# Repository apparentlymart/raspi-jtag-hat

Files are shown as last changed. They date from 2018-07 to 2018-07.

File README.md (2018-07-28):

# Raspberry Pi 3 Bare Metal Dev HAT

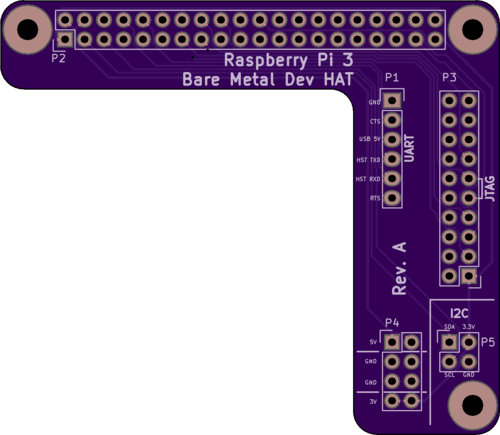
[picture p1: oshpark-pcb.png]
Bare Metal Dev HAT PCB


This repository contains KiCad design files for an **experimental** Raspberry
Pi "pseudo-HAT" (lacking an ID EEPROM) that breaks out the JTAG and UART pins
to an ARM-style JTAG header and a 6-pin "FTDI header" respectively. The goal
is to make it easy to connect diagnostic tools from a host development machine
when working on bare-metal software for the Raspberry Pi 3.

The author makes no promises or warranty about the quality or functionality of
this PCB design. Your mileage may vary. However, if you would like to give it a
try, either clone the repo and load the project into KiCad or download the
Gerber files attached to one of the
[tagged revisions](https://github.com/apparentlymart/raspi-jtag-hat/releases).
Before spending any time and money, please consider checking for any
[open issues](https://github.com/apparentlymart/raspi-jtag-hat/issues), and
for any _closed_ issues that apply to the tagged revision you are working with.

The board also includes extra breakouts for the I2C pins and the power pins
from the main header, as an optional convenience. It might also work for
Raspberry Pi 2, but its unusual L-shape is intended to avoid conflicts with
the larger heatsinks that some owners fit to their Raspberry Pi 3 units.

The following is an example BOM for some through-hole components that could
be used to populate this PCB:

| Ref. | Description | Octopart Id |
| ---- | --- | --- |
| P1 | "FTDI-style" UART header | [22-28-4063-molex-278209](https://octopart.com/22-28-4063-molex-278209) |
| P2 | Raspberry Pi Main header socket | [hif3h-40da-2.54dsa(71)-hirose-22821340](https://octopart.com/hif3h-40da-2.54dsa%2871%29-hirose-22821340) |
| P3 | "ARM-style" JTAG socket | [htst-110-01-l-d-samtec-6823793](https://octopart.com/htst-110-01-l-d-samtec-6823793) |
| P4 | Misc. Power header | [10-89-7082-molex-20831](https://octopart.com/10-89-7082-molex-20831) |
| P5 | I2C header | [10-89-7042-molex-35512](https://octopart.com/10-89-7042-molex-35512) |
| n/a  | Board Spacer (optional) | [mdlsp3-6-01-essentra-33826524](https://octopart.com/mdlsp3-6-01-essentra-33826524) |

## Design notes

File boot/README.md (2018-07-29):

# JTAG init kernel

This directory contains the source code for a very small kernel.img that just
prints a greeting message to the UART, enables the ALT4 functions on the JTAG
pins, and then halts the CPU awaiting instructions from a connected JTAG
adapter.

To build it you will need an `aarch64-linux-gnu` toolchain including `gcc`,
`as`, `ld`, and `objcopy`. Ubuntu Xenial has packages for this named
`gcc-4.8-aarch64-linux-gnu` or `gcc-4.9-aarch64-linux-gnu`.

Build by running `make`, populate the boot partition of your Raspberry Pi
SD card with
[the standard Raspberry Pi firmware](https://github.com/raspberrypi/firmware/tree/master/boot),
and then copy the contents of the generated `bootfs` subdirectory into the boot
partition. This will overwrite two files in the stock firmware:
[the `config.txt` file](https://www.raspberrypi.org/documentation/configuration/config-txt/)
and the Linux kernel image for the Pi 1, Pi Zero, and Compute Module.

The `config.txt` contains `enable_jtag_gpio=1`, which actually enables the
JTAG pin functions earlier on suitably-modern firmware. The code in `kernel.img`
will then configure the pin functions again to make sure.

If all goes to plan and you have a terminal program listening to the UART
you should see the following message on the serial port at boot:

```
Enabling JTAG
```

To make use of this you will need a build of OpenOCD that has `aarch64` support
and a Raspberry Pi 3 target file. At the time of writing neither is included
in a released version of OpenOCD, but you can build
[daniel-k's fork](https://github.com/daniel-k/openocd) (branch armv8) to get
the necessary support to launch OpenOCD. Since I'm using a
[Segger J-Link](https://www.segger.com/products/debug-probes/j-link/) adapter,
my launch command is as follows. You will need to change the first path
to a different interface configuration if you are using a different adapter.

```
openocd -f interface/jlink.cfg -f target/rpi3.cfg
```

With OpenOCD running you can connect an aarch64-targeting `gdb` to the OpenOCD
gdbserver:

```
$ aarch64-linux-gnu-gdb
GNU gdb (GDB) 8.1
Copyright (C) 2018 Free Software Foundation, Inc.
License GPLv3+: GNU GPL version 3 or later <http://gnu.org/licenses/gpl.html>
This is free software: you are free to change and redistribute it.
There is NO WARRANTY, to the extent permitted by law.  Type "show copying"
and "show warranty" for details.
This GDB was configured as "--host=x86_64-pc-linux-gnu --target=aarch64-linux-gnu".
Type "show configuration" for configuration details.
For bug reporting instructions, please see:
<http://www.gnu.org/software/gdb/bugs/>.
Find the GDB manual and other documentation resources online at:
<http://www.gnu.org/software/gdb/documentation/>.
For help, type "help".
Type "apropos word" to search for commands related to "word".
(gdb) file yourprogram.elf
Reading symbols from toyos.elf...done.
(gdb) monitor targets rpi3.cpu
(gdb) monitor halt
(gdb) load_image yourprogram.img 0 bin
(gdb) monitor reset halt
(gdb) monitor reg pc 0
(gdb) c
```

In the above `yourprogram.elf` and `yourprogram.img` are both different forms
of the program you wish to run and debug on the Raspberry Pi 3. The former is
in ELF format and used locally by `gdb`, while the latter is the raw binary
image that is loaded into the Raspberry Pi's memory and executed.

The `monitor` commands run direct OpenOCD commands. You can run `monitor help`
to see the usage information for all of these.

Once you get `gdb` working and get comfortable with it you can load and execute
bare metal code on your Raspberry Pi directly from your development machine,
without constantly swapping and rewriting SD cards, configuring netboot, etc.

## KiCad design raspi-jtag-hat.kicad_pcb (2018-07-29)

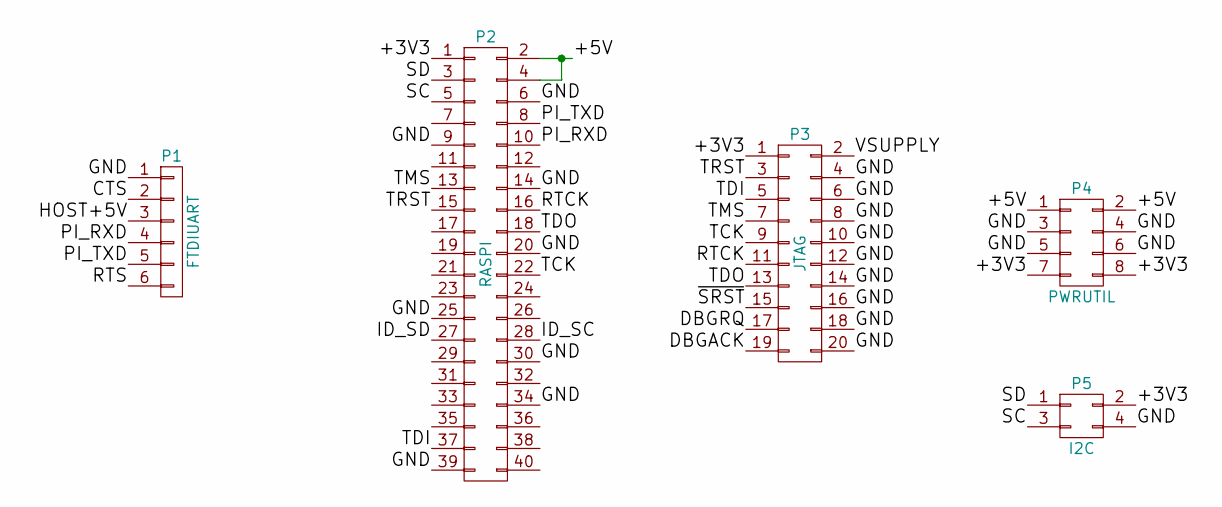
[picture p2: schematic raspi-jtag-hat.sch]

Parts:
P1: FTDIUART
P2: RASPI
P3: JTAG
P4: PWRUTIL
P5: I2C

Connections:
/+3V3: P2.1, P3.1, P4.7, P4.8, P5.2
/+5V: P2.2, P2.4, P4.1, P4.2
/CTS: P1.2
/DBGACK: P3.19
/DBGRQ: P3.17
/GND: P1.1, P2.6, P2.9, P2.14, P2.20, P2.25, P2.30, P2.34, P2.39, P3.4, P3.6, P3.8, P3.10, P3.12, P3.14, P3.16, P3.18, P3.20, P4.3, P4.4, P4.5, P4.6, P5.4
/HOST+5V: P1.3
/ID_SC: P2.28
/ID_SD: P2.27
/PI_RXD: P1.4, P2.10
/PI_TXD: P1.5, P2.8
/RTCK: P2.16, P3.11
/RTS: P1.6
/SC: P2.5, P5.3
/SD: P2.3, P5.1
/TCK: P2.22, P3.9
/TDI: P2.37, P3.5
/TDO: P2.18, P3.13
/TMS: P2.13, P3.7
/TRST: P2.15, P3.3
/VSUPPLY: P3.2
/~SRST: P3.15

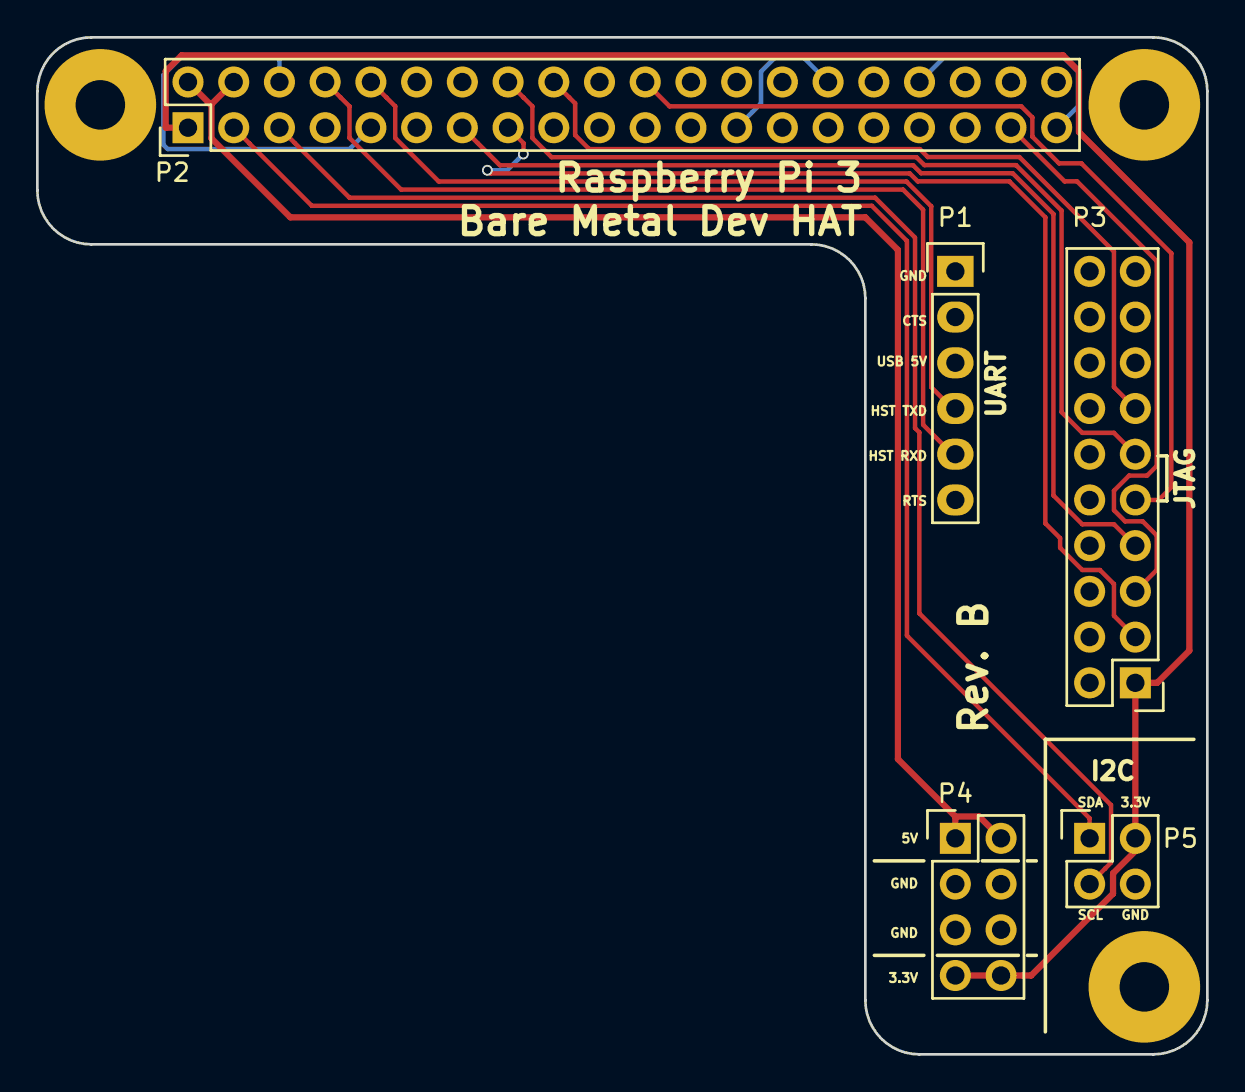
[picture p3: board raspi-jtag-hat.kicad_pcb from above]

Board: 2 copper layers, 65.0 x 56.5 mm, 5 parts (0 on the bottom side), 13 nets.

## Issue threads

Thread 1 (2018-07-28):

JTAG connector is vertically mirrored

apparentlymart, 2018-07-28:
In the Revision A design, the JTAG connector positions are vertically mirrored such that the JTAG connector would need to attach underneath the board rather than on top.

This is physically impossible when mounted on top of a Raspberry Pi as intended. All of the pin positions should be flipped vertically so that pin 1 is at the top right of the connector when viewing the board from the top side.

apparentlymart, 2018-07-29:
This was a false alarm: my test setup was the one that was vertically mirrored. Revision A appears to have the connector correctly oriented after all.

Closed 2018-07-29.

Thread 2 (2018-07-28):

JTAG connector may interfere with Pi 3+ PoE header

apparentlymart, 2018-07-28:
The Raspberry Pi 3+ design introduced a new PoE header just under the top right mounting hole on the main Pi board.

I have not yet verified whether the JTAG connector interferes with either of the lower pins on that connector. Based on the reported positions it seems possible that the top right connector on the header could short to the bottom right pin on the PoE header.

To be determined once I have both a Pi 3+ board and a JTAG HAT board at the same time/

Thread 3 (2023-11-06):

Seems to work on Compute Module 4 with the official I/O board

apparentlymart, 2023-11-06:
Today I've been successfully using a previously-assembled Rev B board (by coincidence, the one I used to verify #2) to interact with a Compute Module 4 through the "HAT headers" on the I/O board.

Both the JTAG and UART connections work. Seems that the pinout is the same as for Raspberry Pi 3. Perhaps the next revision should just say "Raspberry Pi Bare Metal Dev HAT" to avoid seeming like it's only for Pi 3.

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

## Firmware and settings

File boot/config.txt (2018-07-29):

arm_control=0x200
kernel=kernel.img
kernel_old=1
disable_commandline_tags=1
enable_jtag_gpio=1

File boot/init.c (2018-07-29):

/*
 * Derived from code:
 *
 * https://github.com/swarren/rpi-3-aarch64-demo
 * Copyright (C) 2012 Vikram Narayananan <vikram186@gmail.com>
 * (C) Copyright 2012-2016 Stephen Warren
 * Copyright (C) 1996-2000 Russell King
 *
 * SPDX-License-Identifier:	GPL-2.0
 *
 * https://github.com/dwelch67/raspberrypi/tree/master/armjtag
 * Copyright (c) 2012 David Welch dwelch@dwelch.com
 */

#include <stdint.h>

#define BIT(x) (1U << (x))

#define PERI_BASE (0x3F000000)

#define MU_BASE (PERI_BASE + 0x00215040)
#define MU_LSR_TX_NOT_FULL (BIT(5))
#define MU_LSR_RX_READY (BIT(0))

#define AUX_ENABLES (PERI_BASE + 0x00215004)
#define AUX_MU_IO_REG (PERI_BASE + 0x00215040)
#define AUX_MU_IER_REG (PERI_BASE + 0x00215044)
#define AUX_MU_IIR_REG (PERI_BASE + 0x00215048)
#define AUX_MU_LCR_REG (PERI_BASE + 0x0021504C)
#define AUX_MU_MCR_REG (PERI_BASE + 0x00215050)
#define AUX_MU_LSR_REG (PERI_BASE + 0x00215054)
#define AUX_MU_MSR_REG (PERI_BASE + 0x00215058)
#define AUX_MU_SCRATCH (PERI_BASE + 0x0021505C)
#define AUX_MU_CNTL_REG (PERI_BASE + 0x00215060)
#define AUX_MU_STAT_REG (PERI_BASE + 0x00215064)
#define AUX_MU_BAUD_REG (PERI_BASE + 0x00215068)

#define GPFSEL0 (PERI_BASE + 0x00200000)
#define GPFSEL1 (PERI_BASE + 0x00200004)
#define GPFSEL2 (PERI_BASE + 0x00200008)
#define GPSET0 (PERI_BASE + 0x0020001C)
#define GPCLR0 (PERI_BASE + 0x00200028)
#define GPPUD (PERI_BASE + 0x00200094)
#define GPPUDCLK0 (PERI_BASE + 0x00200098)
#define GPPUDCLK1 (PERI_BASE + 0x0020009C)

#define GPFSEL_PIN_MASK (7U) //(BIT(2) | BIT(1) | BIT(0))
#define GPFSEL_ALT_4 (3U)    //(BIT(1) | BIT(0))
#define GPFSEL_ALT_5 (2U)    //(BIT(1))

#define __arch_getl(a) (*(volatile unsigned int *)(a))
#define __arch_putl(v, a) (*(volatile unsigned int *)(a) = (v))

#define dmb() __asm__ __volatile__("dmb st" : : : "memory")
#define nop() __asm__ __volatile__("nop")
#define wfi() __asm__ __volatile__("wfi")
#define __iormb() dmb()
#define __iowmb() dmb()

struct bcm283x_mu_regs {
    uint32_t io;
    uint32_t iir;
    uint32_t ier;
    uint32_t lcr;
    uint32_t mcr;
    uint32_t lsr;
    uint32_t msr;
    uint32_t scratch;
    uint32_t cntl;
    uint32_t stat;
    uint32_t baud;
};

static inline uint32_t readl(uint64_t addr)
{
    uint32_t value = __arch_getl(addr);
    __iormb();
    return value;
}

static inline void writel(uint64_t addr, uint32_t value)
{
    __arch_putl(value, addr);
    __iowmb();
}

static void bcm283x_mu_serial_putc(const char data)
{
    struct bcm283x_mu_regs *regs = (struct bcm283x_mu_regs *)MU_BASE;

    /* Wait until there is space in the FIFO */
    while (!(readl((uint64_t)&regs->lsr) & MU_LSR_TX_NOT_FULL))
        ;

    /* Send the character */
    writel((uint64_t)&regs->io, data);
}

static void dbg_puts(const char *s)
{
    while (*s)
        bcm283x_mu_serial_putc(*s++);
}

static void enable_af_pins(int clock, uint32_t bitmask)
{
    uint32_t clock_reg;
    int i;

    switch (clock) {
    case 0:
        clock_reg = GPPUDCLK0;
        break;
    case 1:
        clock_reg = GPPUDCLK1;
        break;
    default:
        return;
    }

    writel(GPPUD, 0);

    for (i = 0; i < 150; i++)
        nop();

    writel(clock_reg, bitmask);

    for (i = 0; i < 150; i++)
        nop();

    writel(clock_reg, 0);
}

static void enable_jtag()
{
    uint32_t gpfsel2;

    gpfsel2 = readl(GPFSEL2);
    gpfsel2 &= ~(GPFSEL_PIN_MASK << 6);  // Gpio22
    gpfsel2 |= (GPFSEL_ALT_4 << 6);      // Alt4: ARM_TRST
    gpfsel2 &= ~(GPFSEL_PIN_MASK << 9);  // Gpio23
    gpfsel2 |= (GPFSEL_ALT_4 << 9);      // Alt4: ARM_RTCK
    gpfsel2 &= ~(GPFSEL_PIN_MASK << 12); // Gpio24
    gpfsel2 |= (GPFSEL_ALT_4 << 12);     // Alt4: ARM_TDO
    gpfsel2 &= ~(GPFSEL_PIN_MASK << 15); // Gpio25
    gpfsel2 |= (GPFSEL_ALT_4 << 15);     // Alt4: ARM_TCK
    gpfsel2 &= ~(GPFSEL_PIN_MASK << 18); // Gpio26
    gpfsel2 |= (GPFSEL_ALT_4 << 18);     // Alt4: ARM_TDI
    gpfsel2 &= ~(GPFSEL_PIN_MASK << 21); // Gpio27
    gpfsel2 |= (GPFSEL_ALT_4 << 21);     // Alt4: ARM_TMS
    writel(GPFSEL2, gpfsel2);

    enable_af_pins(
        0, BIT(22) | BIT(23) | BIT(24) | BIT(25) | BIT(26) | BIT(27));
}

static void uart_init(void)
{
    writel(AUX_ENABLES, 1);       // enable UART peripheral
    writel(AUX_MU_IER_REG, 0);    // disable UART interrupts for config
    writel(AUX_MU_CNTL_REG, 0);   // disable UART RX/TX for config
    writel(AUX_MU_LCR_REG, 3);    // 8 bit mode (bit 1 reserved!)
    writel(AUX_MU_MCR_REG, 0);    // RTS line high
    writel(AUX_MU_IER_REG, 0);    // disable UART interrupts
    writel(AUX_MU_IIR_REG, 0xC6); // enable and clear FIFOs
    writel(AUX_MU_BAUD_REG, 270); // 115200 Baud

    uint32_t gpfsel1;

    gpfsel1 = readl(GPFSEL1);
    gpfsel1 &= ~(GPFSEL_PIN_MASK << 12); // Gpio14
    gpfsel1 |= (GPFSEL_ALT_5 << 12);     // Alt5: UART_TXD
    gpfsel1 &= ~(GPFSEL_PIN_MASK << 15); // Gpio15
    gpfsel1 |= (GPFSEL_ALT_5 << 15);     // Alt5: UART_RXD
    writel(GPFSEL1, gpfsel1);

    enable_af_pins(0, BIT(14) | BIT(15));

    // enable UART RX/TX again
    writel(AUX_MU_CNTL_REG, 3);
}

int init()
{
    uart_init();
    dbg_puts("\x1b[0;0H\x1b[2J\r\nEnabling JTAG\r\n");
    enable_jtag();

    // Put the CPU to sleep until a debugger connects and wakes it back up
    // again.
    while (1) {
        bcm283x_mu_serial_putc('.');

        for (int i = 0; i < 1000000; i++)
            wfi();
    }
}

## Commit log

2018-07-28 Initial import
    [raspi-jtag-hat.kicad_pcb, raspi-jtag-hat.sch]
2018-07-28 Complete the BOM in the README
2018-07-28 Add an example optional board spacer to the BOM
2018-07-29 Add a small kernel that just enables JTAG and halts all CPU cores
    This is handy to quickly get the Pi up and running with the JTAG pin ALT
    functions enabled so the real work of loading the target program can be
    done over JTAG with OpenOCD/gdb.
    [config.txt]
2018-07-29 Schematic library cache file
    I just missed this on the first round of commits.
2018-07-29 Makefile for automating a "release" of the stuff in here
    This uses the KiCad pcbnew Python interface to render Gerber files, builds
    the boot filesystem files, and then produces two zip files that can be
    attached to a published release for a new revision.
2018-07-29 Change 3.3V header silkscreen caption to "3.3V"
    Previously it said just "3V".
    [raspi-jtag-hat.kicad_pcb]
2018-07-29 Update board silkscreen in preparation for Rev. B.
    [raspi-jtag-hat.kicad_pcb]
2018-07-29 Suppress edge lines on other layers when generating Gerber files
